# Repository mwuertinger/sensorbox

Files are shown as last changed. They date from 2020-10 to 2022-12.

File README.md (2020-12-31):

# Sensorbox
ESP8266 powered CO2, temperature, humidity and pressure sensor.

Displays the measurements on an OLED display and shows CO2 levels with green, yellow and red LEDs.
In addition measurements are sent via MQTT and collected with mqtt2influx.

## Software
The software is written in C++ and built using platformio.

Building:
```
platformio run
```

Installing to a board connected via USB:
```
platformio run --target upload
```

### Configuration
Configuration must happen in src/config.h before building.

## Hardware
The PCB was designed with KiCad. The following parts are required:

### Parts
- 1x D1 Mini NodeMCU with ESP8266-12F
- 1x MH-Z14A NDIR CO2 Sensor
- 1x GY-BME280 Temperature/Humidity/Pressure Sensor
- 1x 128x64 Pixel 0.96in OLED Display with I2C Interface
- 3x LED
- 3x 2N7002 MOSFETs
- 3x 330Ω
- 2x 4.7kΩ
- 1x Button

### Pictures
#### Rendered PCB
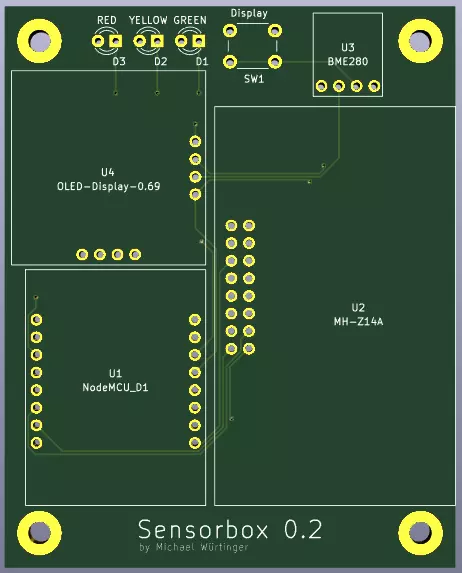
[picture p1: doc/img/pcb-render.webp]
Rendered PCB


#### PCB Front and Back
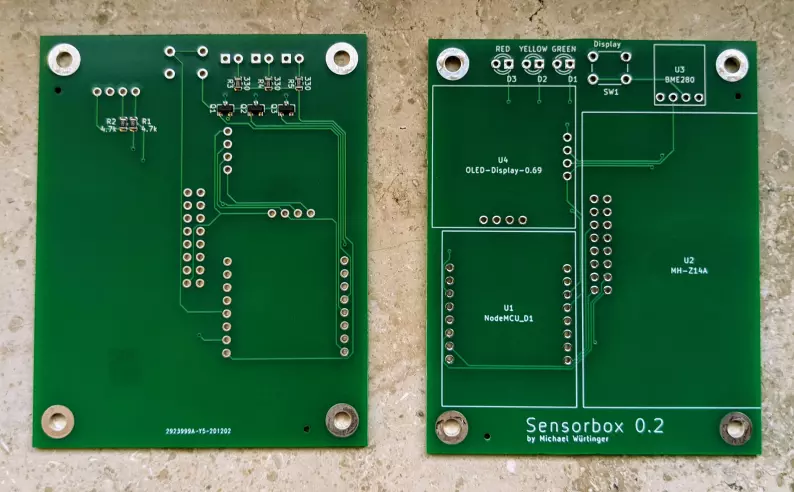
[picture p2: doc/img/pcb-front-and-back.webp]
PCB Front and Back


#### Assembled PCB
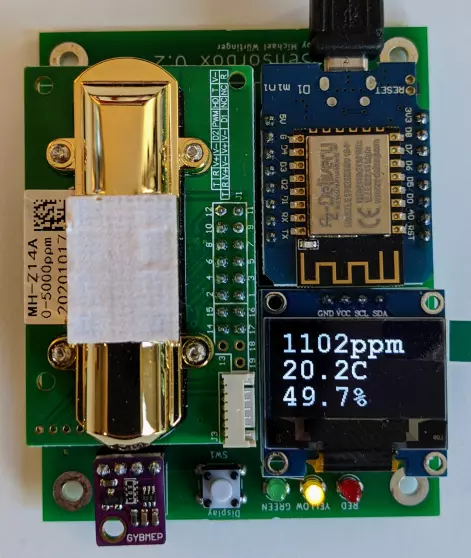
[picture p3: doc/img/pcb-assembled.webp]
Assembled PCB


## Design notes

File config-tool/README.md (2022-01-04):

# Write Config to Device
```
esptool.py --port /dev/ttyUSB0 write_flash 0x03fb000 config.bin
```

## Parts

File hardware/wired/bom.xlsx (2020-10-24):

Comment | Designator | Footprint | LCSC Part #（optional）
4.7kΩ | R1, R2 | 0805_R | C17673
330Ω | R3, R4, R5 | 0805_R | C17630
 | Q1, Q2, Q3 | SOT-23-3 | C8545

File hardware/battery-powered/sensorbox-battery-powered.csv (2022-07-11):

Comment | Designator | Footprint | LCSC
100nF | C1,C3,C5 | Capacitor_SMD:C_0805_2012Metric | C28233
10uF | C2,C4 | Capacitor_SMD:C_0805_2012Metric | C15850
Conn_01x02 | J1 | jst-conectors:JST_PH_S2B-PH-SM4-TB_1x02-1MP_P2.00mm_Horizontal | C295747
Conn_01x06_Male | J2 | Connector_PinHeader_2.54mm:PinHeader_1x06_P2.54mm_Vertical
HT7333-A | L1 | Package_TO_SOT_SMD:SOT-89-3 | C21583
AO3401A | Q1 | Package_TO_SOT_SMD:SOT-23 | C8549
10k | R1,R2,R3,R4,R5,R7,R8 | Resistor_SMD:R_0805_2012Metric | C17414
33k | R6 | Resistor_SMD:R_0805_2012Metric | C17633
Reset | SW1 | Button_Switch_THT:SW_PUSH_6mm
Program | SW2 | Button_Switch_THT:SW_PUSH_6mm
ESP-12F | U1 | ESP8266:ESP-12E_SMD
BME280 | U2 | sensorbox:BME280

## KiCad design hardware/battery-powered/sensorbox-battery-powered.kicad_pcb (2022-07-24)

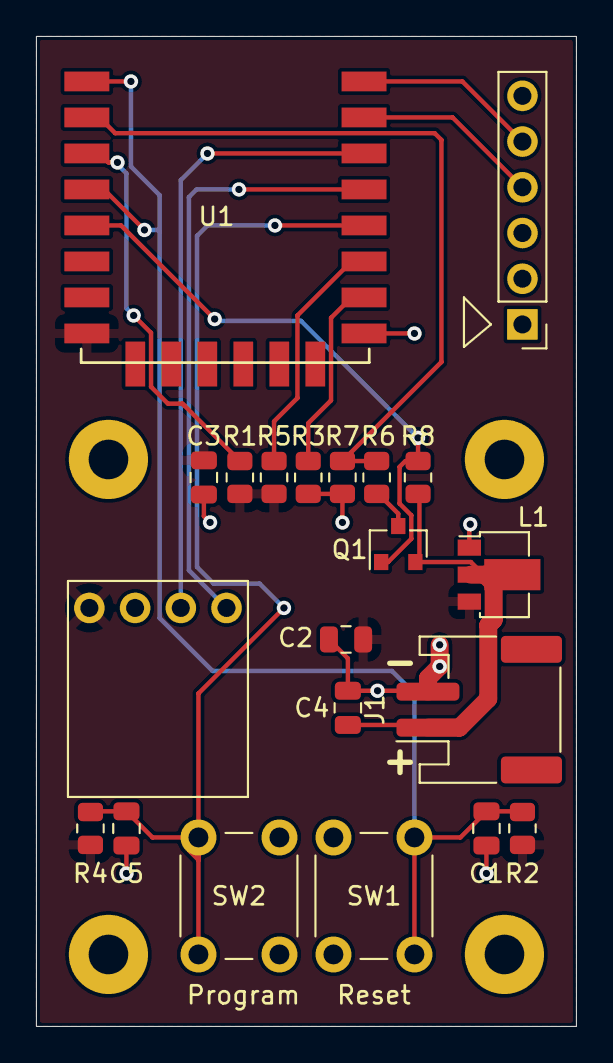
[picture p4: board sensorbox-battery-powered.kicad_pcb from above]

Board: 2 copper layers, 30.0 x 55.0 mm, 21 parts (0 on the bottom side), 15 nets.

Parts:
C1, C3, C5: 100nF; C_0805_2012Metric
C2, C4: 10uF; C_0805_2012Metric
J1: Conn_01x02; JST_PH_S2B-PH-SM4-TB_1x02-1MP_P2.00mm_Horizontal
J2: Conn_01x06_Male; PinHeader_1x06_P2.54mm_Vertical
L1: HT7333-A; SOT-89-3
Q1: AO3401A; SOT-23
R1, R2, R3, R4, R5, R7, R8: 10k; R_0805_2012Metric
R6: 33k; R_0805_2012Metric
SW1: Reset; SW_PUSH_6mm
SW2: Program; SW_PUSH_6mm
U1: ESP-12F; ESP-12E_SMD
U2: BME280

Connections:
+3.3V: C2.1, C3.1, L1.3 (VOUT), R1.2, R2.2, R4.1, R5.1, U1.8 (VCC), U2.1 (VIN)
+BATT: C4.1, J1.1, L1.2 (VIN), Q1.2 (S), R8.1
BAT_SENS: R6.2, R7.1, U1.2 (ADC)
ENABLE_BAT_SENS: Q1.1 (G), R8.2, U1.5 (GPIO14)
GND: C1.1, C2.2, C3.2, C4.2, C5.1, J1.2, J2.1, L1.1 (GND), R3.1, R7.2, SW1.1, SW2.2, U1.9 (GND), U2.2 (GND)
unnamed: C1.2, R2.1, SW1.2, U1.1 (REST), U1.4 (GPIO16)
unnamed: C5.2, R4.2, SW2.1, U1.12 (GPIO0)
unnamed: J2.4, U1.15 (RXD)
unnamed: J2.5, U1.16 (TXD)
unnamed: Q1.3 (D), R6.1
unnamed: R1.1, U1.3 (CH_PD)
unnamed: R3.2, U1.10 (GPIO15)
unnamed: R5.2, U1.11 (GPIO2)
SCL: U1.14 (GPIO5), U2.3 (SCL)
SDA: U1.13 (GPIO4), U2.4 (SDA)

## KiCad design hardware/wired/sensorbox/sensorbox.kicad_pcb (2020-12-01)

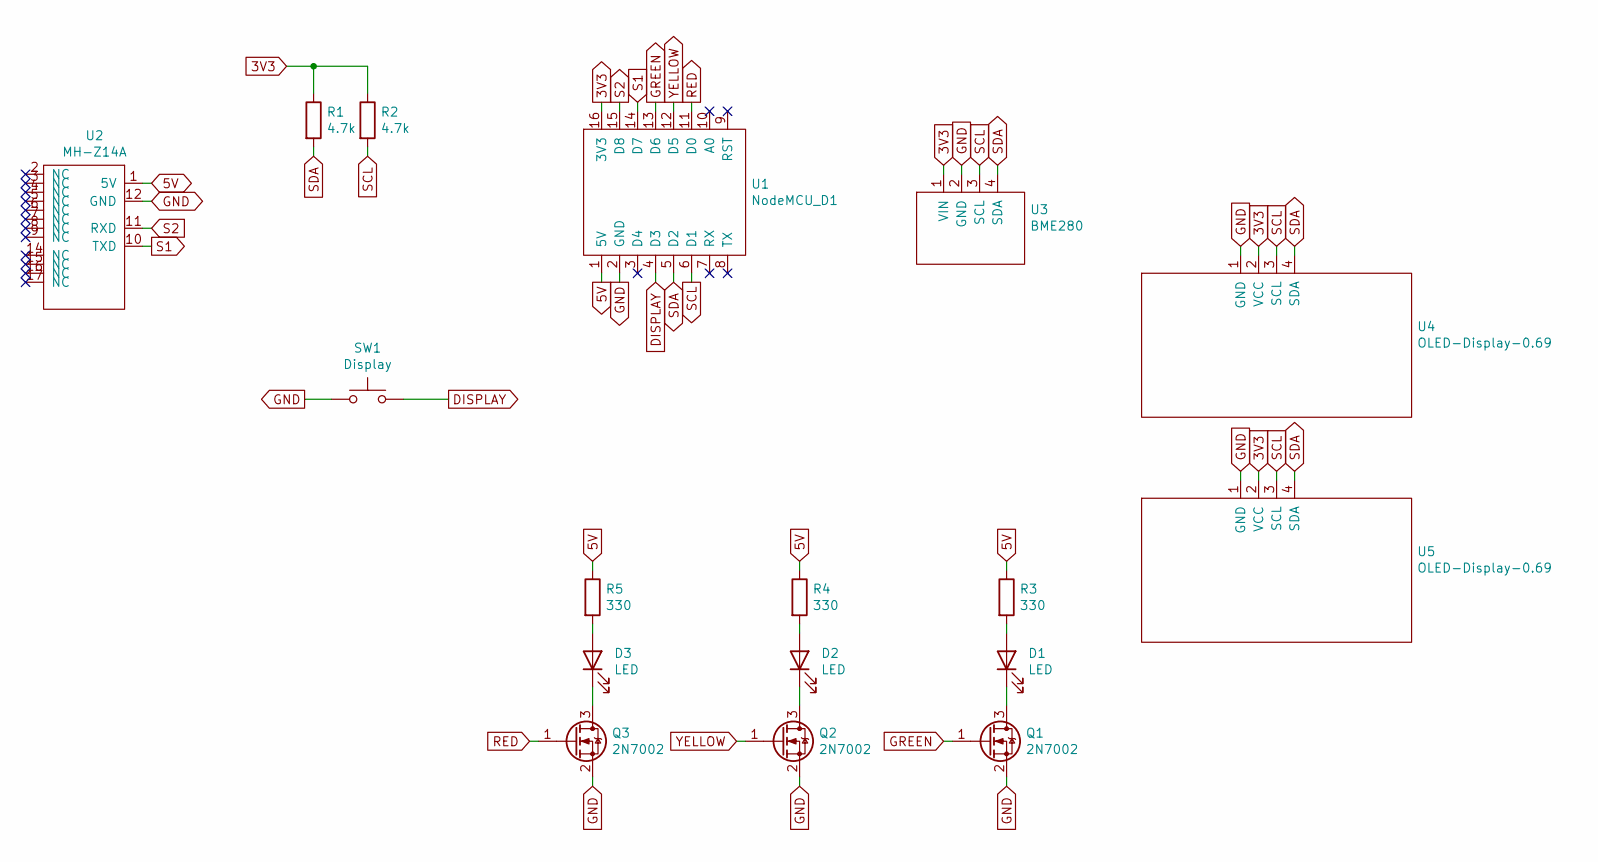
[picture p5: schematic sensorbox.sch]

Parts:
D1, D2, D3: LED; LED_D3.0mm
Q1, Q2, Q3: 2N7002; SOT-23
R1, R2: 4.7k; R_0805_2012Metric
R3, R4, R5: 330; R_0805_2012Metric
SW1: Display; SW_PUSH_6mm
U1: NodeMCU_D1
U2: MH-Z14A
U3: BME280
U4, U5: OLED-Display-0.69

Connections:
3V3: R1.1, R2.1, U1.16 (3V3), U3.1 (VIN), U4.2 (VCC), U5.2 (VCC)
5V: R3.1, R4.1, R5.1, U1.1 (5V), U2.1 (5V)
DISPLAY: SW1.2, U1.4 (D3)
GND: Q1.2 (S), Q2.2 (S), Q3.2 (S), SW1.1, U1.2 (GND), U2.12 (GND), U3.2 (GND), U4.1 (GND), U5.1 (GND)
GREEN: Q1.1 (G), U1.13 (D6)
unnamed: D1.1 (K), Q1.3 (D)
unnamed: D1.2 (A), R3.2
unnamed: D2.1 (K), Q2.3 (D)
unnamed: D2.2 (A), R4.2
unnamed: D3.1 (K), Q3.3 (D)
unnamed: D3.2 (A), R5.2
RED: Q3.1 (G), U1.11 (D0)
S1: U1.14 (D7), U2.10 (TXD)
S2: U1.15 (D8), U2.11 (RXD)
SCL: R2.2, U1.6 (D1), U3.3 (SCL), U4.3 (SCL), U5.3 (SCL)
SDA: R1.2, U1.5 (D2), U3.4 (SDA), U4.4 (SDA), U5.4 (SDA)
YELLOW: Q2.1 (G), U1.12 (D5)

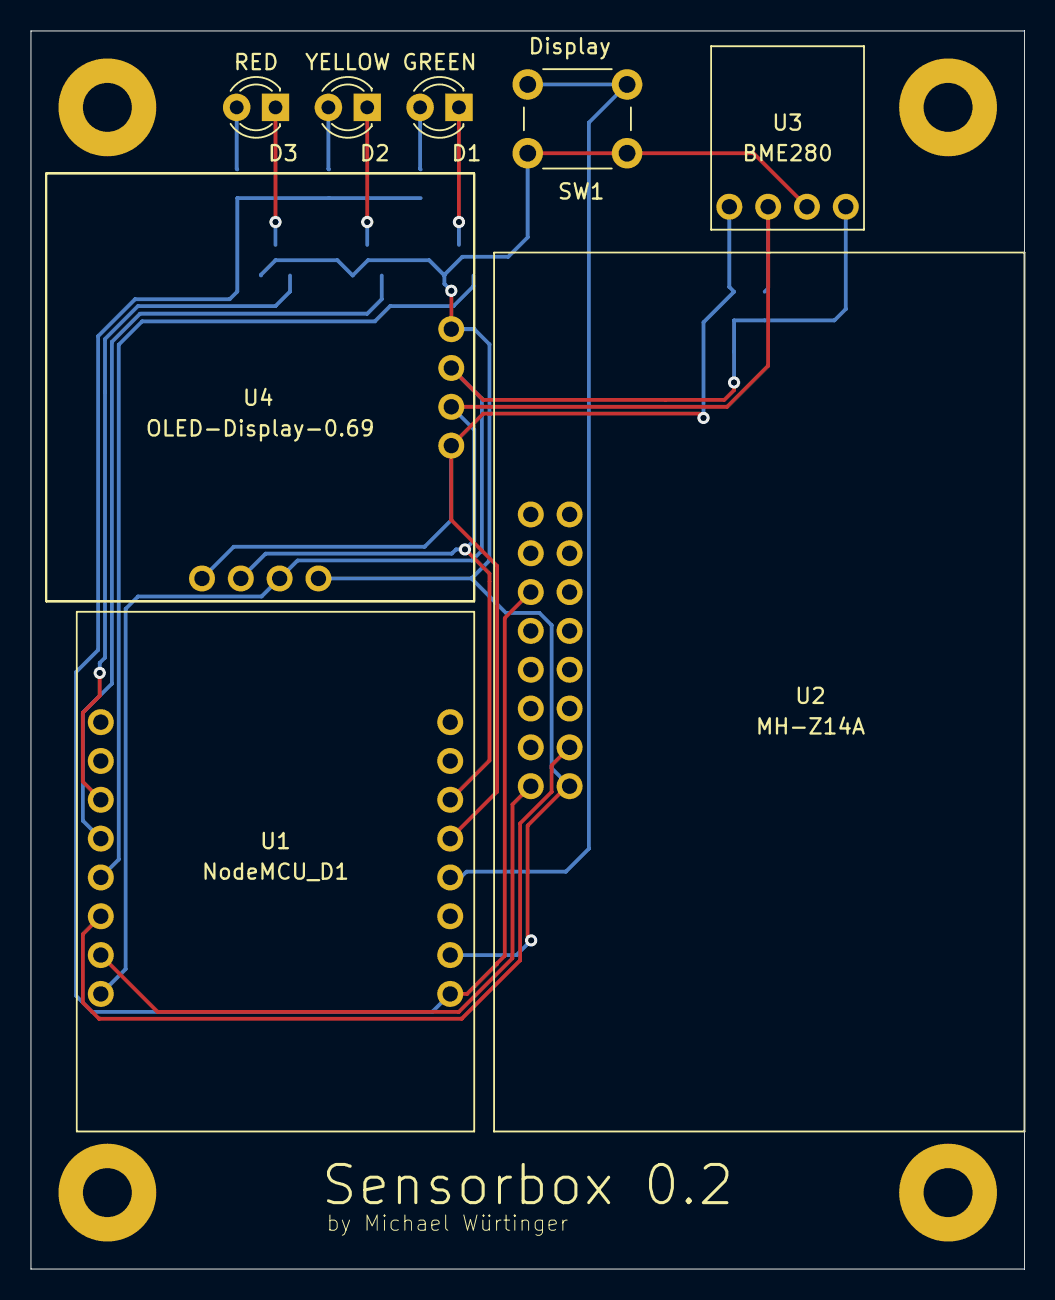
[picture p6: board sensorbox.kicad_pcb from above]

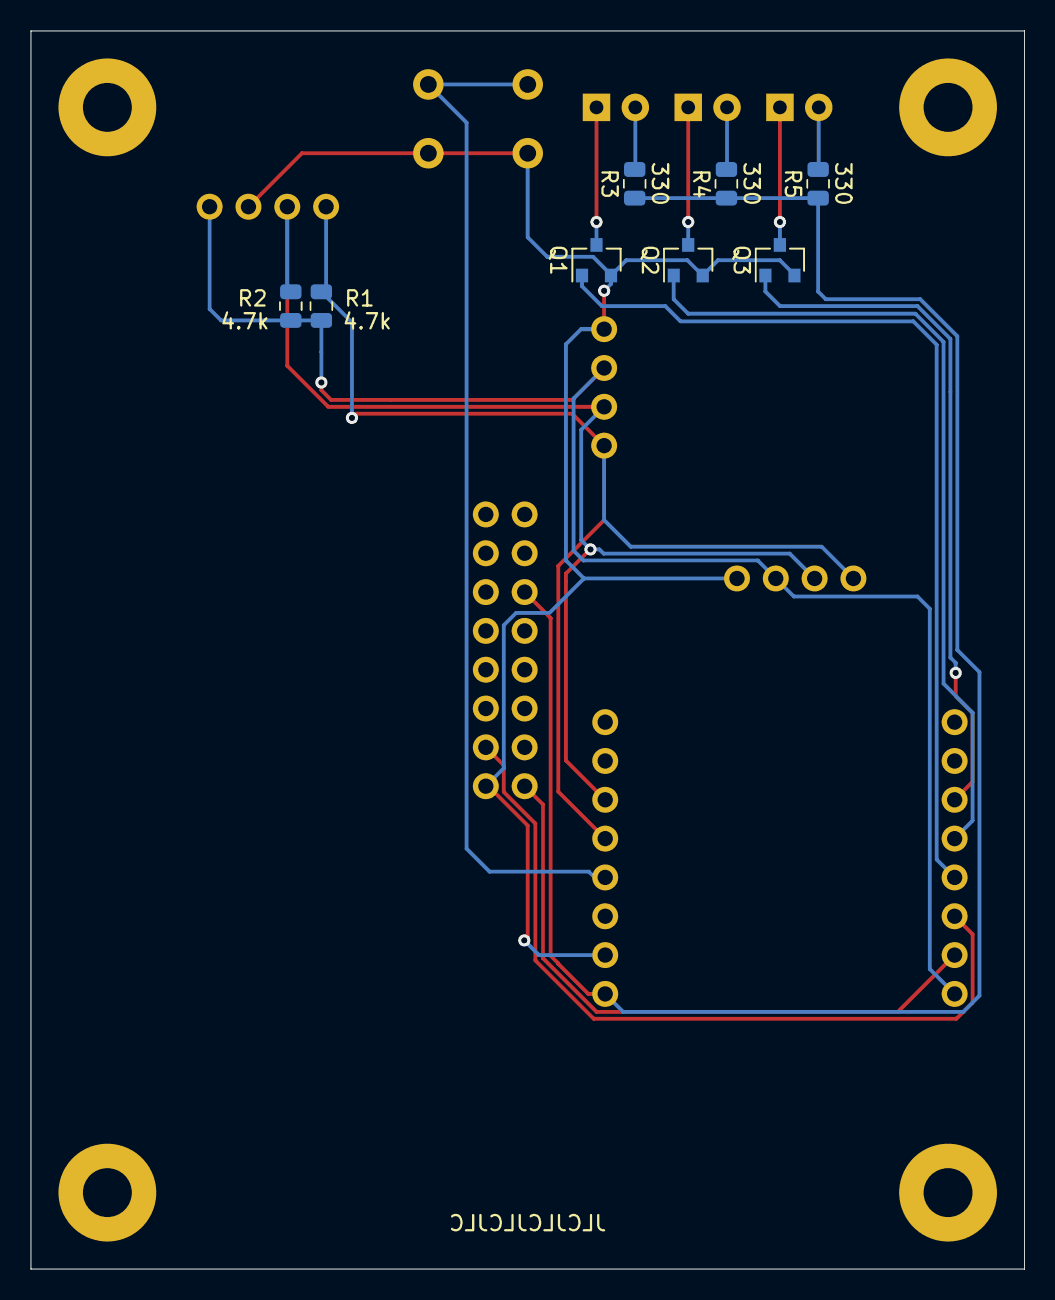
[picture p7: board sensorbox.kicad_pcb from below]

Board: 2 copper layers, 65.0 x 81.0 mm, 17 parts (8 on the bottom side), 17 nets.

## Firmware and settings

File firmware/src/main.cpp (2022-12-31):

#include <Adafruit_BME280.h>
#include "Adafruit_seesaw.h"
#include <Adafruit_Sensor.h>
#include <CRC32.h>
#include <EEPROM.h>
#include <ESP8266WiFi.h>
#include <ESP8266httpUpdate.h>
#include <pb_encode.h>
#include <pb_decode.h>
#include <SoftwareSerial.h>
#include <string.h>
#include <U8g2lib.h>
#include <Wire.h>

#include "sensorbox.pb.h"

#define LED_GREEN D6
#define LED_YELLOW D5
#define LED_RED D0
#define BTN_DISPLAY D3

ConfigPb configPb = ConfigPb_init_zero;

char hostname[64];

float pressure = 0, humidity = 0, temperature = 0, batteryVoltage = 0;
uint16_t co2 = 0, soilMoisture = 0;

Adafruit_BME280 bme;
bool bmeInitialized = false;

// 0: off, 1: display+leds, 2: leds only
uint8_t display = 1;

Adafruit_seesaw ss;

SoftwareSerial co2Sensor(13, 15);

time_t lastUpdate = 0;

unsigned long displayLastTrigger = 0;

U8G2_SSD1306_128X64_NONAME_F_HW_I2C u8g2(U8G2_R0, U8X8_PIN_NONE);

void fatalError(char const *msg) {
  Serial.println(msg);
  if (configPb.hasLeds) {
    while (true) {
      digitalWrite(LED_GREEN, HIGH);
      digitalWrite(LED_YELLOW, LOW);
      digitalWrite(LED_RED, LOW);
      delay(200);
      digitalWrite(LED_GREEN, LOW);
      digitalWrite(LED_YELLOW, HIGH);
      digitalWrite(LED_RED, LOW);
      delay(200);
      digitalWrite(LED_GREEN, LOW);
      digitalWrite(LED_YELLOW, LOW);
      digitalWrite(LED_RED, HIGH);
      delay(200);
    }
  } else {
    for (int i = 0; i < 3; i++) {
      digitalWrite(LED_BUILTIN, HIGH);
      delay(200);
      digitalWrite(LED_BUILTIN, LOW);
      delay(200);
    }
    delay(500);
  }
}

void setupConfig() {
  Serial.println("setupConfig()");
  const size_t EEPROM_SIZE = 1024;
  EEPROM.begin(EEPROM_SIZE);

  // data layout:
  // 4 bytes = message length
  // 4 bytes = CRC checksum
  // protocol buffers message
  uint32_t *pMessageLength = (uint32_t *) EEPROM.getDataPtr();
  uint32_t *pMessageChecksum = (uint32_t *) (EEPROM.getDataPtr() + 4);
  uint8_t *data = EEPROM.getDataPtr() + 8; // skip length and checksum field
  Serial.printf("setupConfig(): *pMessageLength=%d\n\r", *pMessageLength);

  uint32_t checksum = 42;
  if (*pMessageLength < EEPROM_SIZE) {
    Serial.printf("setupConfig(): calculating checksum\n\r");
    CRC32 crc;
    for (size_t i = 0; i < *pMessageLength; i++) {
      crc.update(data[i]);
    }
    checksum = crc.finalize();
  }
  if (checksum != *pMessageChecksum) {
    fatalError("setupConfig: Config checksum error!");
  }

  uint32_t message_length = *pMessageLength;
  Serial.printf("setupConfig: Read message_length=%d\r\n", message_length);
  pb_istream_t stream = pb_istream_from_buffer(data, message_length);
  bool status = pb_decode(&stream, ConfigPb_fields, &configPb);
  if (status) {
    Serial.println("setupConfig: Config decoded successfully");
  } else {
    fatalError("setupConfig: Config decoding failed!");
  }
}

void setupLeds() {
  if (!configPb.hasLeds) {
    return;
  }
  Serial.println("setupLeds");
  pinMode(LED_GREEN, OUTPUT);
  pinMode(LED_YELLOW, OUTPUT);
  pinMode(LED_RED, OUTPUT);
  digitalWrite(LED_GREEN, LOW);
  digitalWrite(LED_YELLOW, LOW);
  digitalWrite(LED_RED, LOW);
}

void setupDisplay() {
  if (!configPb.hasDisplay) {
    return;
  }

  u8g2.begin();
  u8g2.clearBuffer();
  u8g2.setFontRefHeightExtendedText();
  u8g2.setDrawColor(1);
  u8g2.setFontPosTop();
  u8g2.setFontDirection(0);
}

void updateDisplay() {
  if (!configPb.hasDisplay) {
    return;
  }

  u8g2.clearBuffer();
  if (display != 1) {
    u8g2.sendBuffer();
    return;
  }

  u8g2.setFont(u8g2_font_courB18_tf);

  char str[128];

  if (co2 != 0) {
    snprintf(str, 128, "%dppm", co2);
  } else {
    snprintf(str, 128, "---");
  }
  u8g2.drawStr(0, 0, str);
  snprintf(str, 128, "%.1fC", temperature - 273.15);
  u8g2.drawStr(0, 23, str);
  snprintf(str, 128, "%.1f%%\n", humidity);
  u8g2.drawStr(0, 46, str);

  u8g2.sendBuffer();
}

void updateLeds() {
  if (!configPb.hasLeds) {
    return;
  }
  Serial.println("updateLeds");
  if (display == 0) {
    digitalWrite(LED_GREEN, LOW);
    digitalWrite(LED_YELLOW, LOW);
    digitalWrite(LED_RED, LOW);
  } else if (co2 == 0) {
    digitalWrite(LED_GREEN, LOW);
    digitalWrite(LED_YELLOW, LOW);
    digitalWrite(LED_RED, LOW);
  } else if (co2 < 1000) {
    digitalWrite(LED_GREEN, HIGH);
    digitalWrite(LED_YELLOW, LOW);
    digitalWrite(LED_RED, LOW);
  } else if (co2 < 2000) {
    digitalWrite(LED_GREEN, LOW);
    digitalWrite(LED_YELLOW, HIGH);
    digitalWrite(LED_RED, LOW);
  } else {
    digitalWrite(LED_GREEN, LOW);
    digitalWrite(LED_YELLOW, LOW);
    digitalWrite(LED_RED, HIGH);
  }
}

IRAM_ATTR void onDisplay() {
  // debounce by ignoring interrupts for 100ms
  if (millis() - displayLastTrigger < 100) {
    return;
  }
  display = (display + 1) % 3;
  displayLastTrigger = millis();
  Serial.printf("display = %d\n\r", display);

  updateDisplay();
  updateLeds();
}

void setupButton() {
  if (configPb.hasDisplay) {
    pinMode(BTN_DISPLAY, INPUT_PULLUP);
    attachInterrupt(digitalPinToInterrupt(BTN_DISPLAY), onDisplay, RISING);
  }
}

void setupWiFi() {
  Serial.print("Connecting to WiFi");

  if (configPb.hasDisplay) {
    u8g2.setFont(u8g2_font_t0_11_tf);
    u8g2.clearBuffer();
    u8g2.drawStr(0, 0, hostname);
    u8g2.drawStr(0, 12, "Connecting to WiFi...");
    u8g2.sendBuffer();
  }

  WiFi.setAutoReconnect(true);
  WiFi.hostname(hostname);
  WiFi.begin(configPb.wlan_ssid, configPb.wlan_password);
  while (WiFi.status() != WL_CONNECTED) {
    delay(500);
    Serial.print(".");
  }
  Serial.println(WiFi.localIP());
  if (configPb.hasDisplay) {
    u8g2.clearBuffer();
    u8g2.drawStr(0, 0, hostname);
    u8g2.drawStr(0, 12, WiFi.localIP().toString().c_str());
    u8g2.sendBuffer();
  }
}

void onOtaStart() {
  Serial.println("OTA begin");
  if (configPb.hasDisplay) {
    u8g2.clearBuffer();
    u8g2.setFont(u8g2_font_t0_15_tf);
    u8g2.drawStr(4, 0, "Updating...");
    u8g2.drawFrame(4, 20, 120, 20);
    u8g2.sendBuffer();
  }
}

void onOtaEnd() {
  Serial.println("OTA end");
}

void onOtaProgress(int cur, int total) {
  Serial.printf("OTA progress: %d/%d\r\n", cur, total);
  if (configPb.hasDisplay) {
    u8g2.drawBox(4, 20, int(float(cur) / float(total) * 120.0), 20);
    u8g2.sendBuffer();
  }
}

void onOtaError(int err) {
  Serial.printf("OTA error: %d\r\n", err);

  if (configPb.hasDisplay) {
    char str[128];
    snprintf(str, 128, "Error: %d", err);
    u8g2.drawStr(0, 50, str);
    u8g2.sendBuffer();
  }
}

void setupOta() {
  ESPhttpUpdate.setLedPin(LED_BUILTIN, LOW);
  ESPhttpUpdate.onStart(onOtaStart);
  ESPhttpUpdate.onEnd(onOtaEnd);
  ESPhttpUpdate.onProgress(onOtaProgress);
  ESPhttpUpdate.onError(onOtaError);
}

void setupSensors() {
  if (configPb.hasSensorBME280) {
    // default i2c address 0x76
    if (bme.begin(0x76)) {
      bmeInitialized = true;
    } else {
      Serial.println("BME setup failed!");
    }
  }

  if (configPb.hasSensorCo2) {
    co2Sensor.begin(9600);
  }

  if (configPb.hasSensorSeesaw) {
    ss.begin(0x36);
  }
}

void calibrateCo2() {
  if (!configPb.hasSensorCo2) {
    Serial.printf("No CO2 sensor configured\r\n");
    return;
  }
  Serial.printf("Calibrating CO2 sensor\r\n");
  uint8_t cmdCalibrate[] = {0xFF, 0x01, 0x87, 0x00, 0x00, 0x00, 0x00, 0x00, 0x78};
  size_t res = co2Sensor.write(cmdCalibrate, 9);
  if (res != 9) {
    Serial.printf("CO2 sensor: writing failed: %d\r\n", res);
    return;
  }
  co2Sensor.flush();
}

void setup() {
  Serial.begin(9600);
  setupConfig();
  setupLeds();
  snprintf(hostname, 64, "sensorbox%02d", configPb.devId);
  setupButton();
  setupDisplay();
  setupWiFi();
  setupOta();
  setupSensors();
}

size_t buildRequest(uint8_t *buf, size_t length) {
  Request request = Request_init_zero;
  request.devId = configPb.devId;
  strncpy(request.authToken, configPb.authToken, sizeof(request.authToken));
  request.has_measurement = true;
  request.measurement.pressure = pressure;
  request.measurement.humidity = humidity;
  request.measurement.temperature = temperature;
  request.measurement.co2 = co2;
  request.measurement.soilMoisture = soilMoisture;
  request.measurement.batteryVoltage = batteryVoltage;

  pb_ostream_t stream = pb_ostream_from_buffer(buf, length);
  if (!pb_encode(&stream, Request_fields, &request)) {
    Serial.printf("pb_encode failed: %s\r\n", stream.errmsg);
  }
  Serial.printf("pb_encode: length=%d\r\n", stream.bytes_written);
  return stream.bytes_written;
}

void sendRequest(uint8_t *data, size_t length) {
  BearSSL::WiFiClientSecure client;
  client.setFingerprint(configPb.serverFingerprintSha1);
  // client.setSSLVersion(BR_TLS12, BR_TLS12);
  client.setInsecure();

  HTTPClient http;
  if (!http.begin(client,  "https://192.168.178.2:4000/sensorbox")) {
    Serial.println("http.begin failed");
    return;
  }
  int httpCode = http.POST(data, length);
  if (httpCode != HTTP_CODE_OK) {
    Serial.printf("http.POST: %d\r\n", httpCode);
  } else {
    auto response = http.getString();
    Serial.printf("response size: %d\r\n", response.length());
  }

  http.end();
  client.stop();
}

void updateCo2() {
  uint8_t cmdRead[] = {0xFF, 0x01, 0x86, 0x00, 0x00, 0x00, 0x00, 0x00, 0x79};
  size_t res = co2Sensor.write(cmdRead, 9);
  if (res != 9) {
    Serial.printf("CO2 sensor: writing failed: %d\r\n", res);
    return;
  }
  co2Sensor.flush();

  uint8_t buf[9];
  int n = 0;
  // try to read from serial port up to 10000 times
  // usually data arrives after ~1300 iterations
  for (int i = 0; i < 10000 && n < 9; i++) {
    int val = co2Sensor.read();
    if (val < 0) {
      continue;
    }
    buf[n] = val;
    n++;
  }

  // verify checksum
  uint8_t checksum = 0;
  for (uint8_t i = 1; i < 8; i++) {
    checksum += buf[i];
  }
  checksum = 0xFF - checksum;
  checksum += 1;
  if (buf[8] != checksum) {
    Serial.println("CO2 sensor: checksum error!");
  } else {
    co2 = 256 * buf[2] + buf[3];
    if (co2 < 200 || co2 > 10000) {
      Serial.printf("CO2 sensor: discarding implausible value: %d\r\n", co2);
      co2 = 0;
    }
  }
}

void sensorUpdate() {
  time_t now = time(nullptr);
  if (now - lastUpdate < 60) { // update every 60s
    return;
  }
  lastUpdate = now;

  if (bmeInitialized) {
    pressure = bme.readPressure() / 100.0;
    humidity = bme.readHumidity();
    temperature = bme.readTemperature() + 273.15; // convert to Kelvin
  }

  co2 = 0;
  if (configPb.hasSensorCo2) {
    updateCo2();
  }

  soilMoisture = 0;
  if (configPb.hasSensorSeesaw) {
    soilMoisture = ss.touchRead(0);
  }

  if (configPb.hasSensorBatteryVoltage) {
    pinMode(D5, OUTPUT);
    digitalWrite(D5, LOW);
    int voltageRaw = analogRead(A0);
    batteryVoltage = float(voltageRaw) / 1023.0 * 4.2086;
    digitalWrite(D5, HIGH);
  }

  auto buf = new uint8_t[128];
  auto length = buildRequest(buf, 128);
  sendRequest(buf, length);
  delete[] buf;

  updateDisplay();
  updateLeds();
}

void loop() {
  sensorUpdate();

  if (configPb.deepSleepMicroSeconds > 0) {
    Serial.printf("Sleeping for %lld us...\r\n", configPb.deepSleepMicroSeconds);
    bme.setSampling(Adafruit_BME280::MODE_SLEEP);
    ESP.deepSleep(configPb.deepSleepMicroSeconds);
  }
}

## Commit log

2020-03-21 Add CO2 sensor
2020-03-26 Switch to CSV encoding
    The MQTT library has a default message limit of 128 bytes. In order to
    keep messages within this limit it was necessary to switch to a more
    compact representation: CSV. In case this is still too large we could
    even switch to a binary representation.
    In addition the client name is replaced with a client ID to save some
    more space.
    Further changes:
    - Remove co2SensorStartupTime and use uptime instead
    - Report temperature in Kelvin so that we can check represent missing
    values consistently as 0
    - Report uptime to detect reboots
    [main.cpp]
2020-05-22 CO2 measurement plausibility check
    Recently a sensorbox without connected CO2 sensor published a reading of
    26k. Apparently the ESP somehow read random data from the UART and the
    checksum matched by coincidence. To make this less likely implausible
    values are now discarded.
2020-10-11 PCB Draft
    [sensorbox.kicad_pcb, sensorbox.sch]
2020-10-24 Final pcb design
    [sensorbox-B_Cu.gbr, sensorbox-B_Mask.gbr, sensorbox-B_SilkS.gbr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]
2020-10-24 Add BOM and POS files
    [bom.xlsx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]
2020-10-29 Increased all hole sizes to 1mm
    [sensorbox.kicad_pcb]
2020-11-08 LED and display implementation
2020-11-27 Standardize soldering pad sizes and silk screens
2020-11-29 Board redesign
    - Move BME280 far away from MCU
    - Move display, LEDs and button next to each other
    - Rotate MCU to route cable out towards the bottom
    [sensorbox.kicad_pcb, sensorbox.sch]
2020-11-30 Optimize traces.
    [sensorbox.kicad_pcb]
2020-12-01 Add name and author.
    [sensorbox.kicad_pcb]
2020-12-01 Add order number placement label
    [sensorbox.kicad_pcb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]
2020-12-01 Generate new gerber files
    [sensorbox-B_Cu.gbr, sensorbox-B_Mask.gbr, sensorbox-B_SilkS.gbr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]
2020-12-20 Remove CO2 sensor pre-heat delay
2020-12-20 Trigger display button on RISING edge
2020-12-23 Add calibrate_co2 command and use hostname as topic
2021-03-26 Add carriage return to log message
2022-01-04 Support different sensorbox device combinations.
    New fields are added to the config to selectively enable/disable various devices
    which allows new types of sensorboxes.
2022-01-05 Switch to platformio 5.2.4.
2022-07-04 Initial import.
    [sensorbox-battery-powered.kicad_pcb, sensorbox-battery-powered.sch]
2022-07-04 Fix courtyard.
    [sensorbox-battery-powered.kicad_pcb]
2022-07-07 Add battery sensing circuit.
    [sensorbox-battery-powered.kicad_pcb, sensorbox-battery-powered.sch]
2022-07-07 Use SMD battery connector.
    [sensorbox-battery-powered.sch]
2022-07-11 Final design.
    [sensorbox-battery-powered.kicad_pcb]
2022-07-11 Add gerber abd BOM files.
    [sensorbox-battery-powered-B_Cu.gbl, sensorbox-battery-powered-B_Mask.gbs, sensorbox-battery-powered-B_Paste.gbp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]
2022-07-11 Add hardware sub-folder.
    [sensorbox-battery-powered-B_Cu.gbl, sensorbox-battery-powered-B_Mask.gbs, sensorbox-battery-powered-B_Paste.gbp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]
2022-07-13 Replace kicad-ESP8266 with submodule.
2022-07-24 Remove JST connectors libraries.
    [sensorbox-battery-powered.kicad_pcb, sensorbox-battery-powered.kicad_sch, sensorbox-battery-powered.sch]
2022-08-16 Add sensorbox case design.
2022-08-19 Adjust code to support battery powered hardware.
    - Make LEDs optional
    - Add support for voltage measurements
    - Add support for deep sleep
2022-08-30 Add test case for unknown device.
2022-08-30 Remove NTP.
    We do not really have a use for wall clock time and querying it just
    drains the battery.
2022-09-03 Send data to HTTP endpoint.
    - Read server URI, fingerprint and authToken from config.
    - Divide sensorUpdate() into multiple smaller functions to make them
    more readable and to save stack space.
    - Add code to generate and send protobuf message.
    - Remove MQTT based code.
2022-12-31 Fix LEDs and add LED-only mode.
    The new mode allows to turn off the display but keep the LEDs on.
    [main.cpp]
2023-01-28 Add battery alert and opencensus and make client calls async.
2023-01-29 Move battery threshold voltage into config.
